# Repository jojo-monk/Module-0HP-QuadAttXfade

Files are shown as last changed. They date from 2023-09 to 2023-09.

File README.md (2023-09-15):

# Module-0HP-QuadAttXfade
Quadruple attenuateur passif
Testé et Fonctionnel

2 petites erreurs de cablage :
- le potentiometre Mix out que j'ai cablé à l'envers, ainsi que le bouton mute du Mix out.

  Ces erreurs ont été corrigés dans le fichier kicad, et les fichiers gerber.
  Comme je m'en suisapeçu après fabrication, j'ai juste refait une étiquette pour corriger la serigraphie.

2 small wiring errors:
- the Mix out potentiometer that I wired backwards, as well as the Mix out mute button.

   These errors have been corrected in the kicad file, and the gerber files.
   As I noticed after manufacturing, I just made a label again to correct the screen printing.

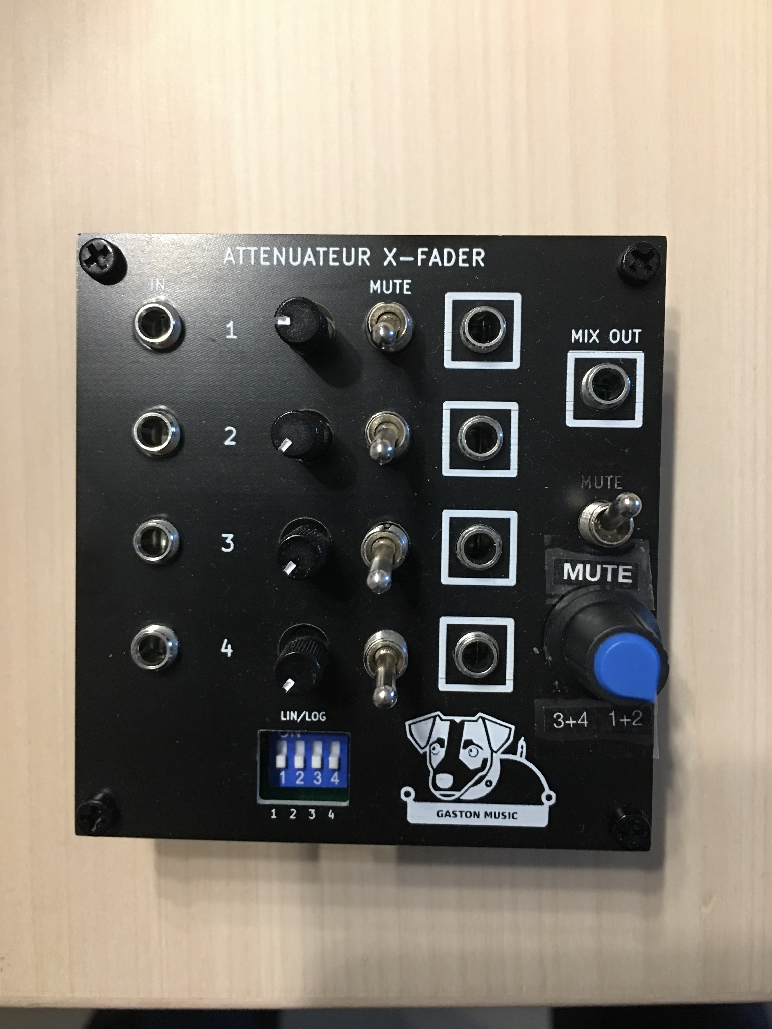
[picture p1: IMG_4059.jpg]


[Build document](https://htmlpreview.github.io/?https://github.com/jojo-monk/Module-0HP-QuadAttXfade/blob/main/ibom.html)

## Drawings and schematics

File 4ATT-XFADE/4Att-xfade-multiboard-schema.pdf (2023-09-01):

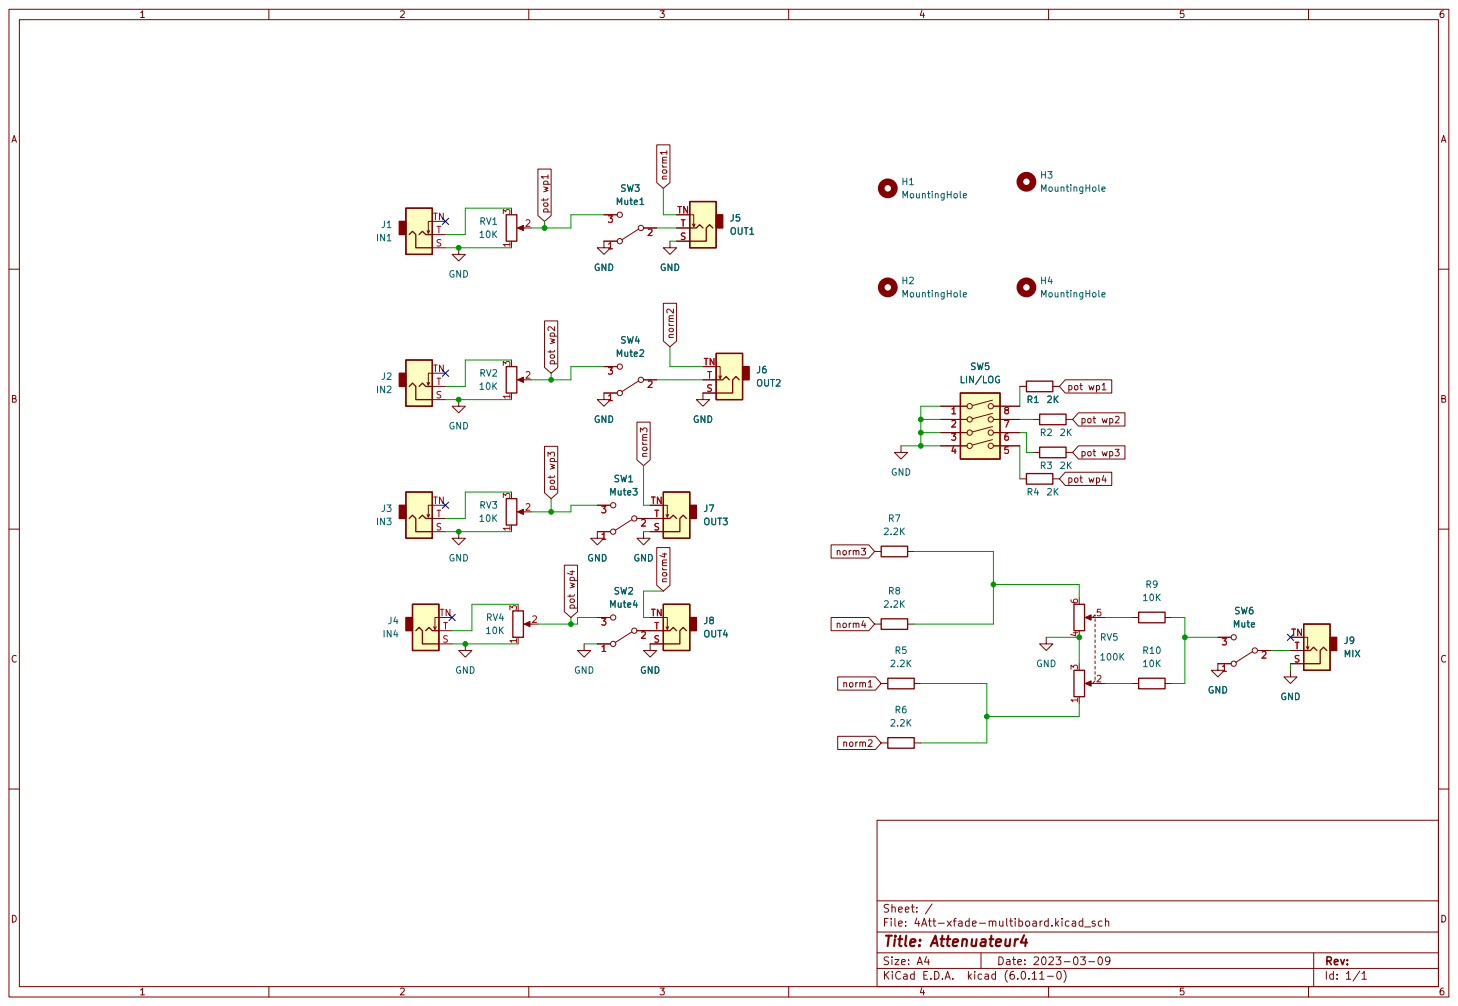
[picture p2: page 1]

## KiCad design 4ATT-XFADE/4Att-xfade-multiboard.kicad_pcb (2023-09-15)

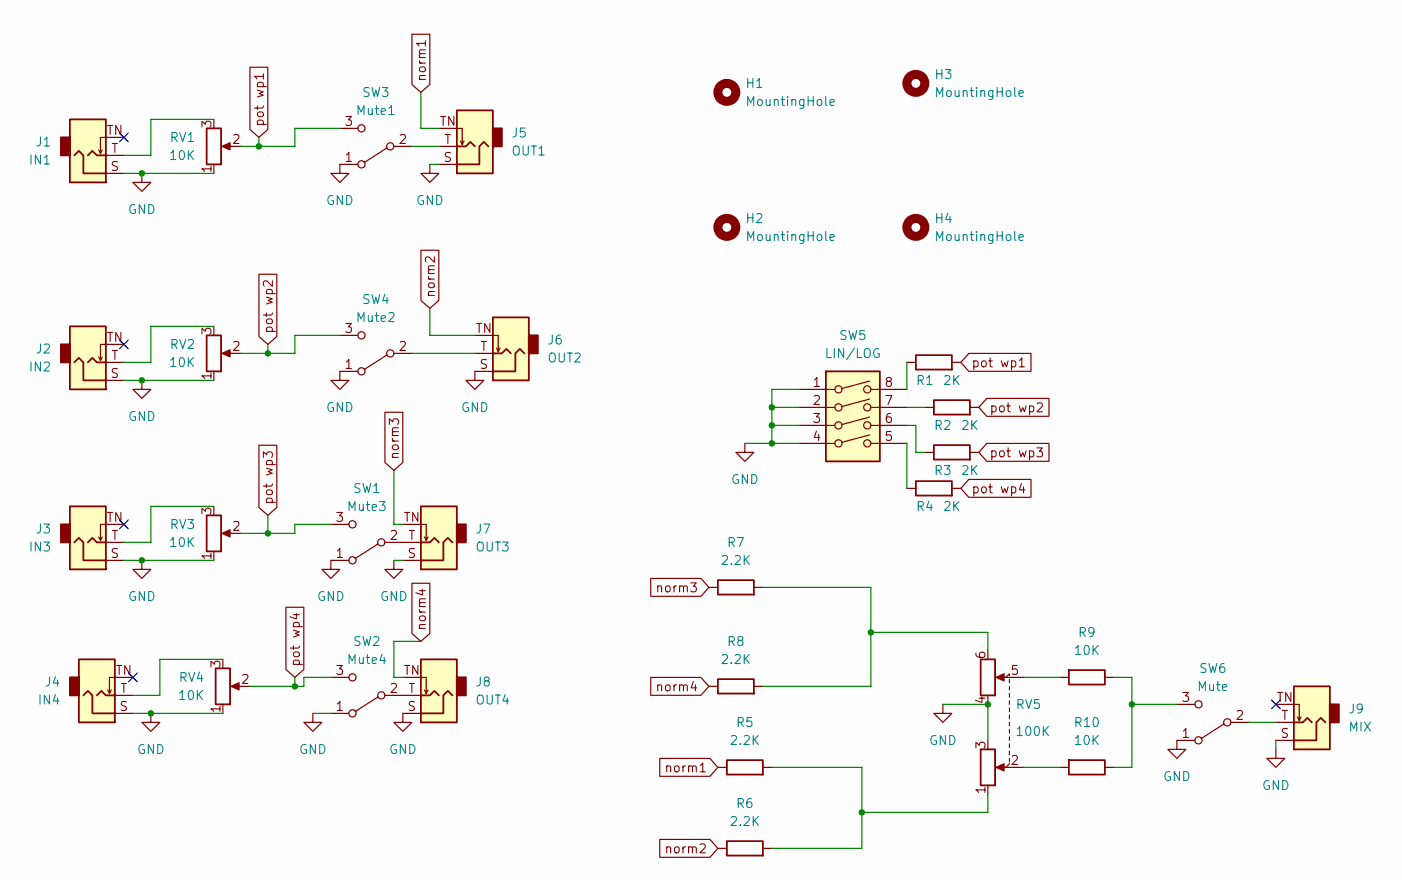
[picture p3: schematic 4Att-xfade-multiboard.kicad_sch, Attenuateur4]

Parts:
H1, H2, H3, H4: MountingHole; MountingHole_3.2mm_M3
J1: IN1; Jack_3.5mm_QingPu_WQP-PJ301M-12_Vertical
J2: IN2; Jack_3.5mm_QingPu_WQP-PJ301M-12_Vertical
J3: IN3; Jack_3.5mm_QingPu_WQP-PJ301M-12_Vertical
J4: IN4; Jack_3.5mm_QingPu_WQP-PJ301M-12_Vertical
J5: OUT1; Jack_3.5mm_QingPu_WQP-PJ301M-12_Vertical
J6: OUT2; Jack_3.5mm_QingPu_WQP-PJ301M-12_Vertical
J7: OUT3; Jack_3.5mm_QingPu_WQP-PJ301M-12_Vertical
J8: OUT4; Jack_3.5mm_QingPu_WQP-PJ301M-12_Vertical
J9: MIX; Jack_3.5mm_QingPu_WQP-PJ301M-12_Vertical
R1, R2, R3, R4: 2K; R_Axial_DIN0207_L6.3mm_D2.5mm_P10.16mm_Horizontal
R5, R6, R7, R8: 2.2K; R_Axial_DIN0207_L6.3mm_D2.5mm_P10.16mm_Horizontal
R9, R10: 10K; R_Axial_DIN0207_L6.3mm_D2.5mm_P10.16mm_Horizontal
RV1, RV2, RV3, RV4: 10K; Potentiometer_Alpha_RD901F-40-00D_Single_Vertical
RV5: 100K; Potentiometer_Alpha_RD902F-40-00D_Dual_Vertical
SW1: Mute3; Switch_Toggle_SPDT_Mini_SolderLug
SW2: Mute4; Switch_Toggle_SPDT_Mini_SolderLug
SW3: Mute1; Switch_Toggle_SPDT_Mini_SolderLug
SW4: Mute2; Switch_Toggle_SPDT_Mini_SolderLug
SW5: LIN/LOG; SW_DIP_SPSTx04_Slide_9.78x12.34mm_W7.62mm_P2.54mm
SW6: Mute; Switch_Toggle_SPDT_Mini_SolderLug

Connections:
GND: J1.S, J2.S, J3.S, J4.S, J5.S, J6.S, J7.S, J8.S, J9.S, RV1.1, RV2.1, RV3.1, RV4.1, RV5.3, RV5.4, SW1.1 (A), SW2.1 (A), SW3.1 (A), SW4.1 (A), SW5.1, SW5.2, SW5.3, SW5.4, SW6.1 (A)
unnamed: J1.T, RV1.3
unnamed: J2.T, RV2.3
unnamed: J3.T, RV3.3
unnamed: J4.T, RV4.3
unnamed: J5.T, SW3.2 (B)
unnamed: J6.T, SW4.2 (B)
unnamed: J7.T, SW1.2 (B)
unnamed: J8.T, SW2.2 (B)
unnamed: J9.T, SW6.2 (B)
unnamed: R1.1, SW5.8
unnamed: R2.1, SW5.7
unnamed: R3.1, SW5.6
unnamed: R4.1, SW5.5
unnamed: R5.2, R6.2, RV5.1
unnamed: R7.2, R8.2, RV5.6
unnamed: R9.2, RV5.5
unnamed: R9.1, R10.1, SW6.3 (C)
unnamed: R10.2, RV5.2
norm1: J5.TN, R5.1
norm2: J6.TN, R6.1
norm3: J7.TN, R7.1
norm4: J8.TN, R8.1
pot wp1: R1.2, RV1.2, SW3.3 (C)
pot wp2: R2.2, RV2.2, SW4.3 (C)
pot wp3: R3.2, RV3.2, SW1.3 (C)
pot wp4: R4.2, RV4.2, SW2.3 (C)

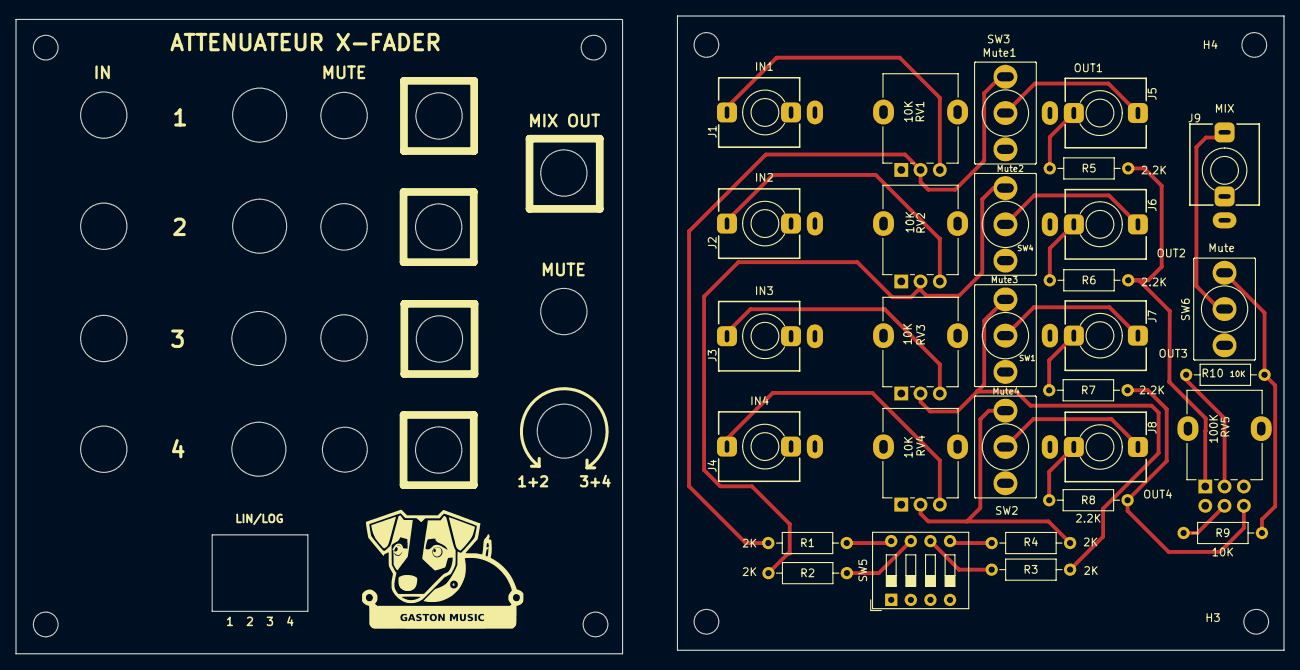
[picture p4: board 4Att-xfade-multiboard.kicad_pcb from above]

Board: 2 copper layers, 78.6 x 82.2 mm, 34 parts (0 on the bottom side), 27 nets.

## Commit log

2023-09-01 correction Mute
    [4Att-xfade-multiboard.kicad_pcb]
2023-09-15 ajout image
    [4Att-xfade-multiboard.kicad_pcb]
